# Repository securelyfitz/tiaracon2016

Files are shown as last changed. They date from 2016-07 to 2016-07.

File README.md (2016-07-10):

# Tiaracon 2016 PCB badge
http://tiaracon.org/
ATtiny-based charlieplexed LED flasher derived from https://git.io/fireflies with different artwork and fancy pcb

## Hardware Description
This project is designed as the badge for tiaracon 2016. The circuit is intended to be a simple soldering project based on the ATTiny using only a handful of through-hole components. It uses 3 I/O pins to drive 6 charlieplexed LEDs, and an additional I/O pin for a mode button.

## Bill of Materials:
* 6x 3mm or 5mm LEDs with .1" spacing
* 3x 150 Ohm Resistor
* 1x ATTiny85 8-DIP
* 1x 20mm CR2032 holder and battery
* 1x 6x6mm SPST-NO mode button

In quantity, BOM cost is just over $2 (unless, like today, ATTinys are $4 each on digikey instead of $1)

##Building
All of the components are labeled right on the board. The ATTiny goes on the BACK of the board, the side with the ponys. Note the location of pin 1. All other components can go on either side, though it seems like LEDS on front and everything else on the back looks best.

##Software Description
This code is an Arduino sketch. I used the Sparkfun TinyAVR Programmer and follow the linked hookup guide to get it working: https://www.sparkfun.com/products/11801

The code for lighting the Charlieplexed LED's is cut and pasted from Jason Webb's project linked above. The code for sensing the capacitive buttons is based on Paul Stoffregen's updated CapacitiveSensor libarry: https://github.com/PaulStoffregen/CapacitiveSensor 

I rely heavily on global variables, and use the state and values to determine what to display on any given iteration. This allows me to responsively check the capsense button without dealing with interrupts.

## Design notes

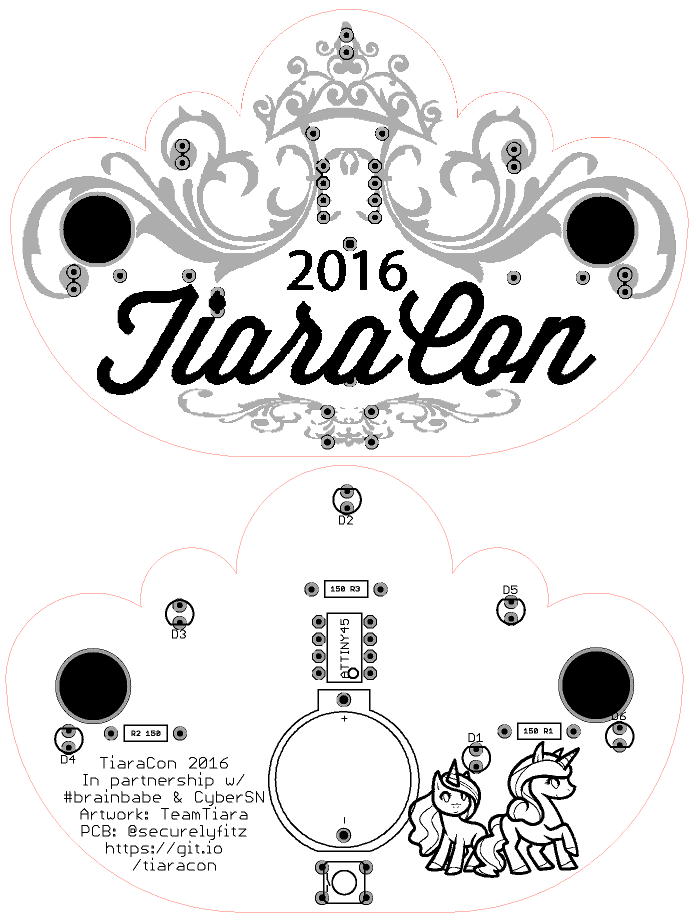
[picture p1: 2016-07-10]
hardware/tiaraconproto.png

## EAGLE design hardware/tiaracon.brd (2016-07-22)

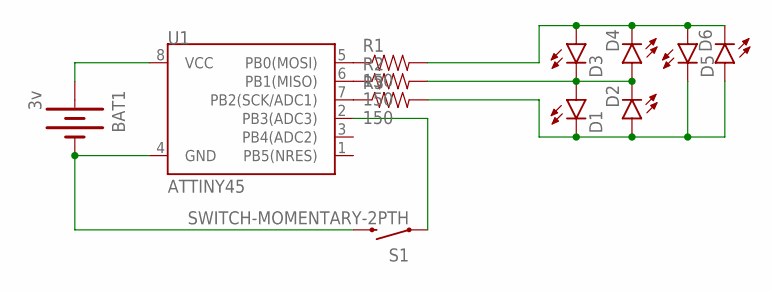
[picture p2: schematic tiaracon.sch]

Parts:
BAT1: 3v; BATTCOM_20MM_PTH
D1, D2, D3, D4, D5, D6: LED3MM
R1, R2, R3: 150; AXIAL-0.4
S1: SWITCH-MOMENTARY-2PTH; TACTILE-PTH
U1: ATTINY45; DIP08

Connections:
GND: BAT1.2 (-), S1.3 (2), U1.4 (GND)
unnamed: R1.P$1 (1), U1.5 (PB0(MOSI))
unnamed: R2.P$1 (1), U1.6 (PB1(MISO))
unnamed: R3.P$1 (1), U1.7 (PB2(SCK/ADC1))
unnamed: S1.1, U1.2 (PB3(ADC3))
unnamed: D3.A, D4.K (C), D5.A, D6.K (C), R1.P$2 (2)
unnamed: D1.K (C), D2.A, D5.K (C), D6.A, R3.P$2 (2)
unnamed: D1.A, D2.K (C), D3.K (C), D4.A, R2.P$2 (2)
VCC: BAT1.1 (+), U1.8 (VCC)

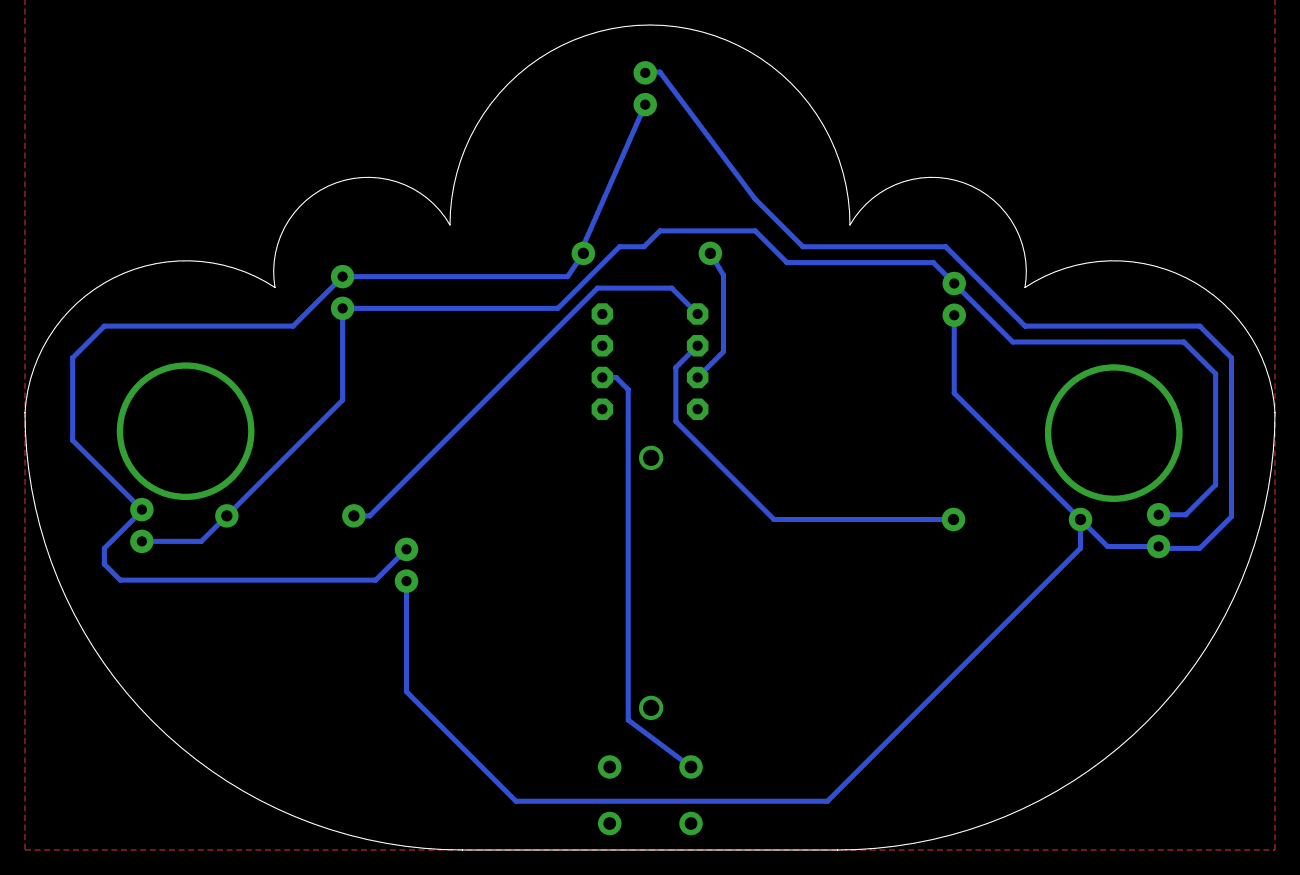
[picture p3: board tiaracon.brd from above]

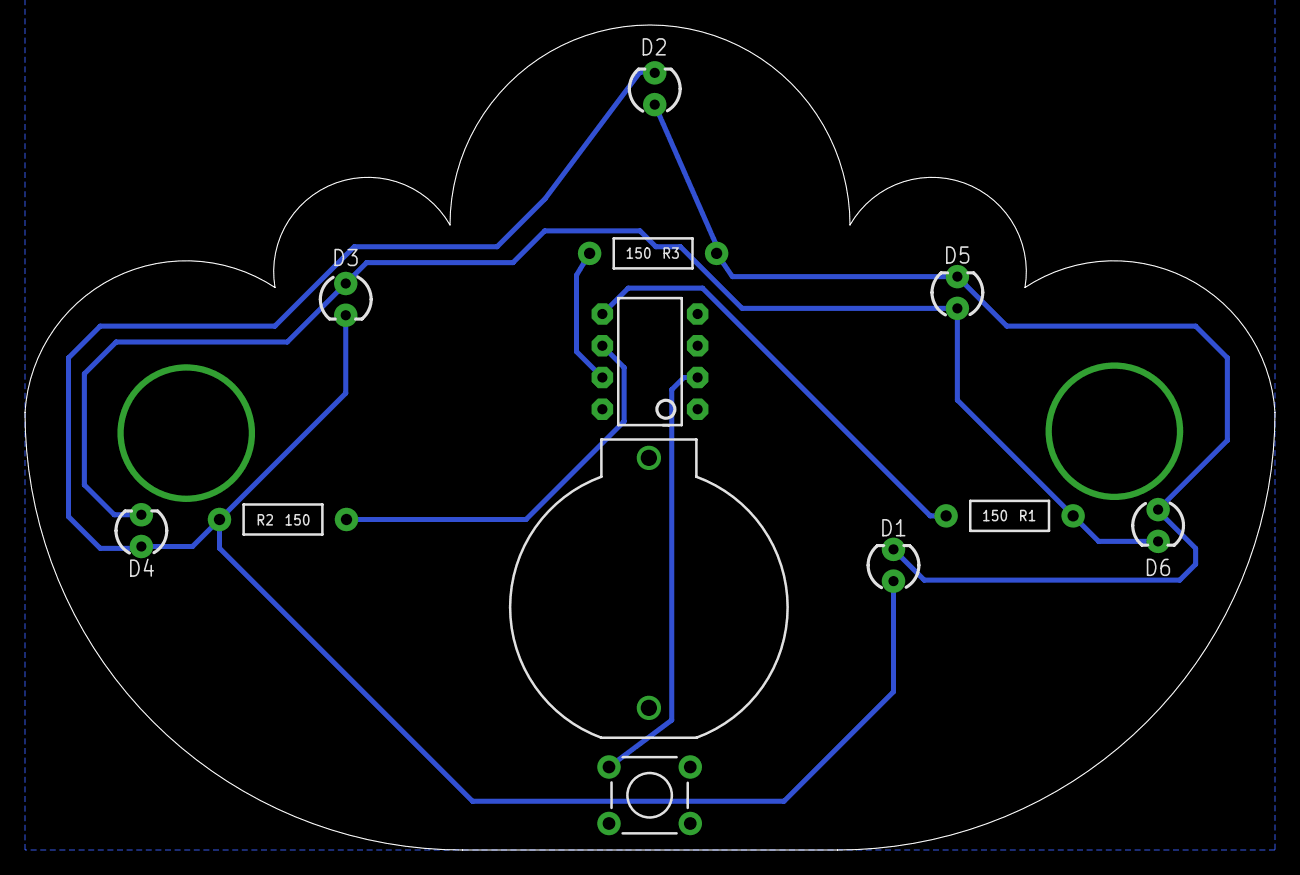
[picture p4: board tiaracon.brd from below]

Board: 2 copper layers, 100.0 x 66.0 mm, 14 parts (13 on the bottom side), 9 nets.

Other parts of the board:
U$1: TIARA
U$2: PONY

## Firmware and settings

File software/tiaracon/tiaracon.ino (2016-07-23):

  
/*
ATTiny code for 2016 Tiaracon Badge
Joe FitzPatrick, @securelyfitz, joefitz@securinghardware.com

Software, hardware, and build notes at https://git.io/tiaracon

Arduino sketch for ATTiny45+ based tiaracon badge. 6 charlieplexed LEDs plus a button
Derived from https://git.io/fireflies which in turn relied heavily on Jason Webb's jar of fireflies:
Github repo: https://github.com/jasonwebb/Jar-of-Fireflies

todos:
DONE--be more consistent with globals vs. passed values
DONE--clean up state change code
DONE--fix 1 vs 2 led option
DONE--switch power modes when in state 0 to prolong standby battery life https://learn.sparkfun.com/tutorials/h2ohno/low-power-attiny
DONE--turn off ADC to save power
DONE--tweak charlieplexing code to mininmize glitches and flashes
--fix PWM code to minimize glitches and flashes.


*/
#include <avr/sleep.h>
#define F_CPU 1000000


// Pin assignments
const byte pinA = 0;
const byte pinB = 1;
const byte pinC = 2;
#define NUMSTATES 6;

int currmode=0;
bool pressed= false;
int currled=0;
unsigned long startmillis=0;
int elapsedmillis=0;

void setup() {
  GIMSK |= _BV(PCIE);                     // Enable Pin Change Interrupts
  PCMSK |= _BV(PCINT3);                   // Use PB3 as interrupt pin
  sei();                                  // enables interrupts
  ADCSRA &= ~_BV(ADEN);                   // ADC off
  set_sleep_mode(SLEEP_MODE_PWR_DOWN);    // everything off

  pinMode(3,INPUT_PULLUP);  //pullup so it's normally high, active low button
}

ISR(PCINT0_vect)
{
  random(6);//adds entropy because its called for every event, even debounced ones
  // if we're not in the pressed state and you press the button, enter the pressed state and increment mode
  if (!digitalRead(3)&&!pressed){pressed=true;currmode++;}
  // if we're in the pressed state, and the button is now released, leave pressed state
  if (digitalRead(3)&&pressed){pressed=false;}
}

void loop() {  
  switch(currmode){
    case 0:    //all on
      for(int j=0; j<6; j++) {
        turnOn(j);
      }
      break;
    case 1:    //I on
      turnOn(5);
      break;
    case 2:    //tiara on
      for(int j=0; j<5; j++) {
        turnOn(j);
      }
      break;
    case 3:   //ordered fade quick
      currled++;
      currled%=6;
      for (int brightness=0;brightness<256;brightness++){
        analogOn(currled, brightness);
      }
      for (int brightness=255;brightness>0;brightness--){
        analogOn(currled, brightness);
      }
      break;
    case 4:   //random fade slow. Set a counter, and calculate LED PWM based on that counter
      //if elapsed time exceeded - pick a led, start a counter
      elapsedmillis=millis()-startmillis;   // calculate elapsed time so we know what to do
      if (startmillis==0){     //this should only hit the very first time we get to this case
        startmillis=millis();
      }else if (elapsedmillis>=4600){   //timeout, choose a new LED and reset our start itme
        startmillis+=elapsedmillis;
        currled=random(6);  
        analogOn(currled,0);
      }else if (elapsedmillis>=4088){   //lights out time
        turnOffAll();
      }else if (elapsedmillis>=2048){   //fade out time
        analogOn(currled,(-8-elapsedmillis)/8);      
      }else{                            //fade in time 
        analogOn(currled,(elapsedmillis)/8);
      }
      break;
    case 5:  // low power mode
      turnOffAll(); 
      //wait until button is released before going to sleep, otherwise we'll just wake back up.
      while(!digitalRead(3)){delay(100);}
      sleep_enable();
      sleep_cpu();
    default: // if we get here by mistake go back to zero.
      currmode=0;
      break;
  }
}

//useful test function to output a value
void flash(int count){
  for(int i=0;i<=count;i++){
    turnOn(1);
    delay(500);
    turnOff(1);
    delay(500);
  }
}

// Turn on a single LED to full brightness
void turnOn(byte led) {
  analogOn(led, 255);
}

// Turn off an LED completely
void turnOff(byte led) {
  analogOn(led, 0);
}

//turns off all LEDs.
void turnOffAll() {
  //go to high impedence mode- disconnect all active power
  pinMode(pinA, INPUT);
  pinMode(pinB, INPUT);
  pinMode(pinC, INPUT);
  //put everything low, so that no power is supplied when they go to output mode
  digitalWrite(pinA, LOW);
  digitalWrite(pinB, LOW);
  digitalWrite(pinC, LOW);
  //clear all pwm setttings, analogWrite calls pinMode(output) before setting the output value!!
  analogWrite(pinA, 0);
  analogWrite(pinB, 0);
  analogWrite(pinC, 0);
  //by now, all pins should be 0v outputs without accidentally turning any on
}
// Write an analog value to an LED.
void analogOn(byte led, byte value) {
//  if (value<8){value=0;}
//  if (value>240){value=255;}
  switch(led) {
    case 4:
      pinMode(pinC, INPUT);
      
      digitalWrite(pinA, LOW);
      pinMode(pinA, OUTPUT);
      
      analogWrite(pinB, value);
      break;
    case 3:
      pinMode(pinC, INPUT);

      digitalWrite(pinB, LOW);
      pinMode(pinB, OUTPUT);
      
      analogWrite(pinA, value);
      break;
    case 5:
      pinMode(pinC, INPUT); // to avoid PinB->PinC current
      pinMode(pinA, INPUT);
      
      analogWrite(pinB, 255-value);
      
      digitalWrite(pinC, HIGH);
      pinMode(pinC, OUTPUT);
      break;
    case 2:
      pinMode(pinA, INPUT);
      
      digitalWrite(pinC, LOW);
      pinMode(pinC, OUTPUT);

      analogWrite(pinB, value);
      break;
    case 1:
      pinMode(pinC, INPUT); // to avoid PinA->PinC current
      pinMode(pinB, INPUT);
      
      analogWrite(pinA, 255-value);

      digitalWrite(pinC, HIGH);
      pinMode(pinC, OUTPUT);
      break;
    case 0:
      pinMode(pinB, INPUT);
      
      digitalWrite(pinC, LOW);
      pinMode(pinC, OUTPUT);

      analogWrite(pinA, value);
      break;
  }
}

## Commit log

2016-07-09 updating filenames
    [tiaracon.brd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]
2016-07-09 adding tiara artwork, inital attempt at rough layout of components. No traces yet.
    [tiaracon.brd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]
2016-07-09 adjusted spacing and alignment, adjusted lanyard hole size - probably too big
2016-07-09 including updated brd and sch files. changed switch to through hole, etc
    [tiaracon.brd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]
2016-07-09 circuit laid out, added ponies and text. still need to adjust lanyard holes
    [tiaracon.brd, tiaracon.sch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]
2016-07-09 final draft. need comments on colors, lanyard hole placement, and text
2016-07-10 final round of changes, pcb to be ordered if approved...
    [tiaracon.brd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]
2016-07-20 fix arduino sketch to use pushbutton instead of touch sensorwqwq
    [tiaracon.ino]
2016-07-22 major software rewrite: -button triggered by interrupt, not polling -reordered commands in analogOn(), putting low/ground values first to avoid charge leakage resulting in random flashing of other le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
    [tiaracon.ino]
2016-07-22 adjusted silkscreen and added note on how to orient LEDs when assembling.
    [tiaracon.brd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]
2016-07-23 all todos completed, including: -fixed some spurious flashing due to poorly ordered charlieplexing commands -fixed slow flash mode to be interruptable -fixed sleep mode to not immediately wake up on 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
    [tiaracon.ino]

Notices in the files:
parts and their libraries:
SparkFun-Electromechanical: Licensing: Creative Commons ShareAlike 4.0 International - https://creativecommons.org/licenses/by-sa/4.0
